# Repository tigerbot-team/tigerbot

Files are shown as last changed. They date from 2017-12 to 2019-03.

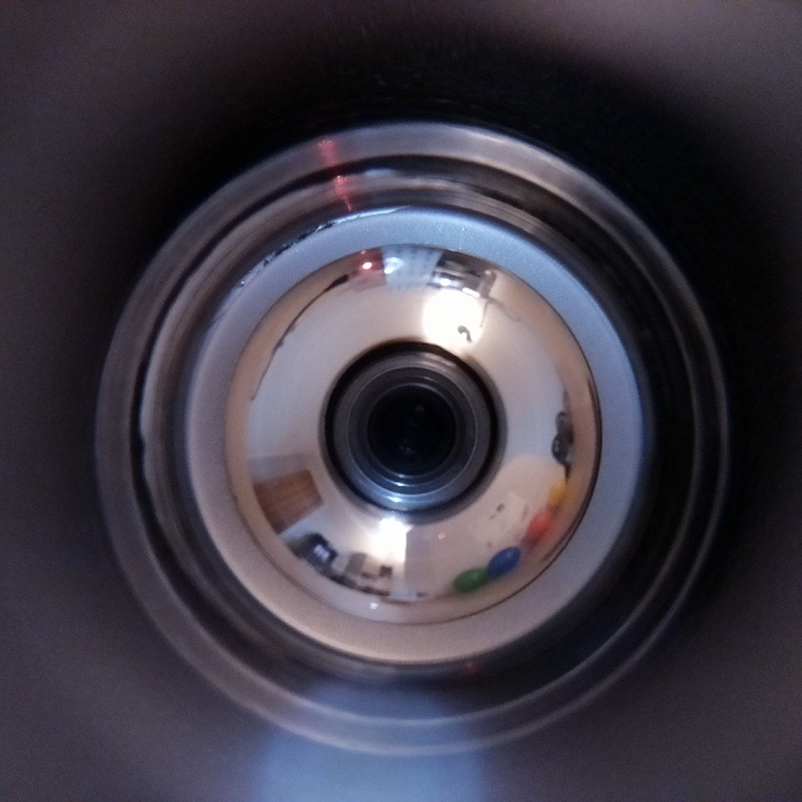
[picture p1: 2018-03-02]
camera-experiments/balls-polar.jpg

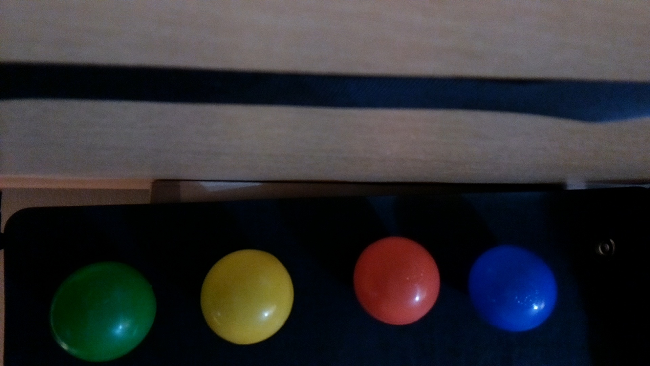
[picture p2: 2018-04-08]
camera-experiments/new-pics/last.jpg

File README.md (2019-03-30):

# tigerbot

- Building:
  - `make go-controller/bin/controller`
    - other targets: `make go-controller/bin/<target>`
   where targets in 
  `controller  ina219tests  joytests  screentests  servotests  spitests  toftests`
- Build image
  - `make go-controller-image`
- install
  - `make go-install-to-pi BOT_HOST=<pi IP>`
  - `make go-patch BOT_HOST=<pi IP>`
- run on Pi
  - ```
       docker run --rm -ti \
       -v `pwd`/controller:/controller \
       -v `pwd`/mb3.binary:/mb3.binary \
       -v /tmp:/tmp \
       -v /dev:/dev \
       --privileged \
       tigerbot/go-controller | tee controller.log
    ```

### Notes
- `toftests` binary needs to run inside container, so mount it in.

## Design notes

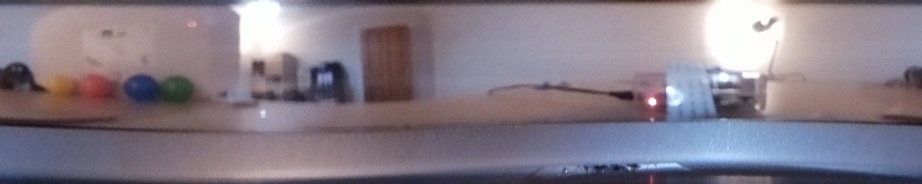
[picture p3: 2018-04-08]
pics/Feb18/unwarped-2031.jpg

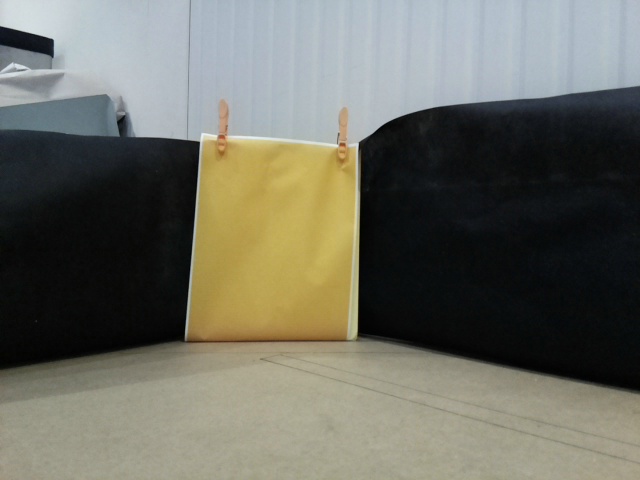
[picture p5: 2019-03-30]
nebula-captures/run-7-fail-yellow-green/nebula-image-4.jpg

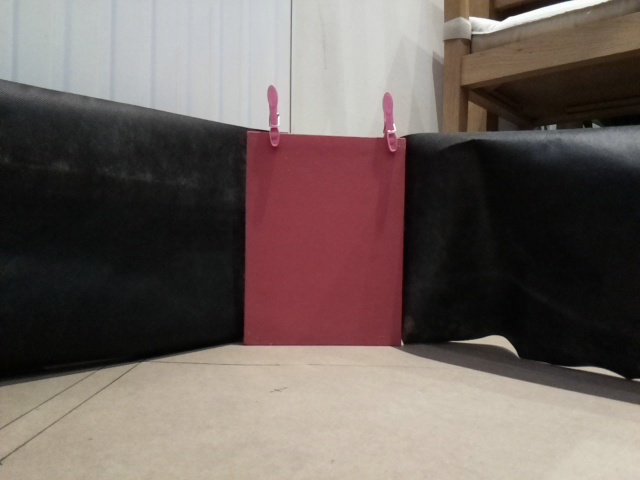
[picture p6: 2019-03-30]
nebula-captures/run-7-fail-yellow-green/nebula-image-1.jpg

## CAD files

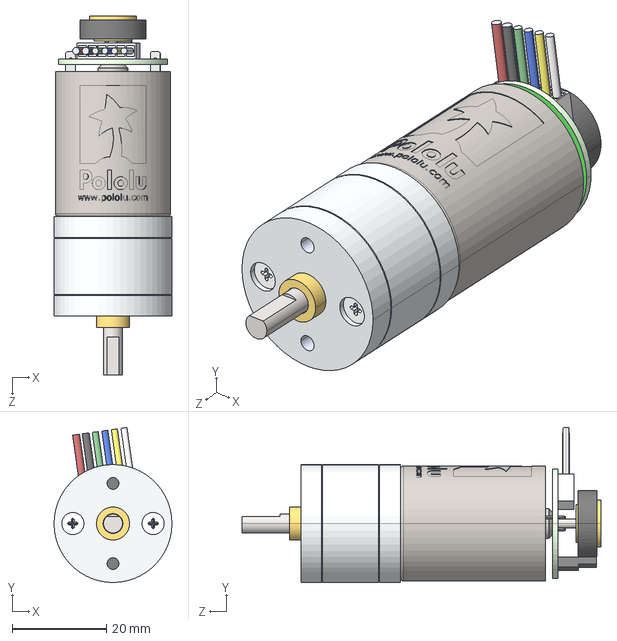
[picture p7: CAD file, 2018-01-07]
printed/cad/25d-metal-gearmotor-34-47-encoder.step
25.0 x 32.9 x 76.0 mm

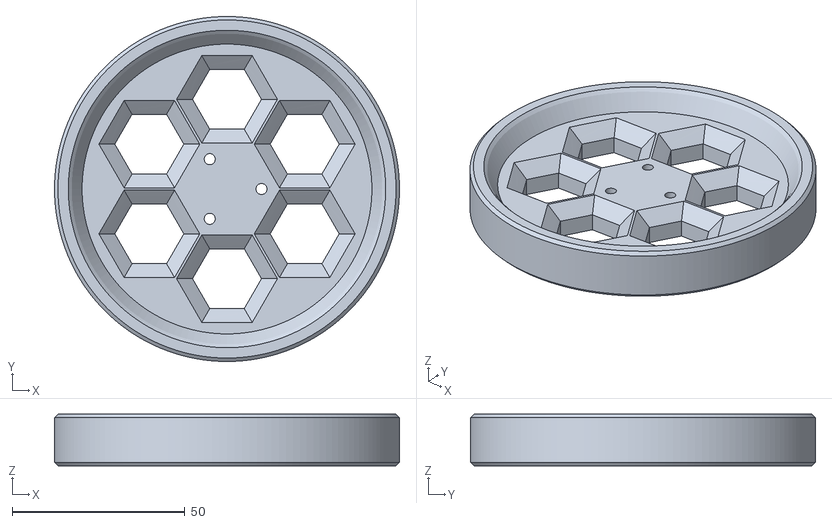
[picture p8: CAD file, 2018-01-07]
printed/stl/Wheel.stl
100.0 x 100.0 x 15.0

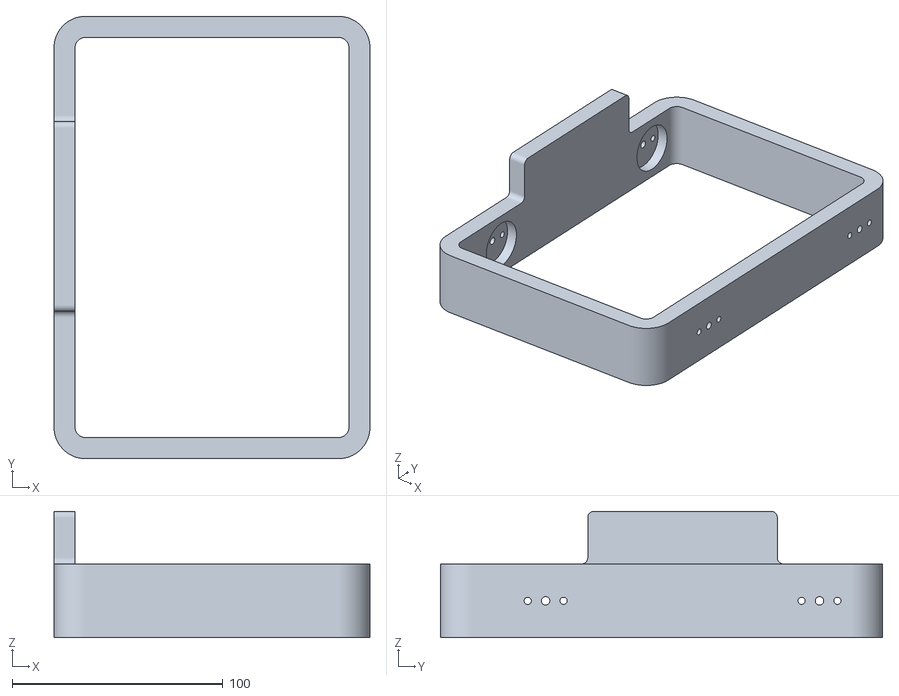
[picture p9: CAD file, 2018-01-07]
printed/stl/Chassis.stl
150.0 x 210.0 x 60.0

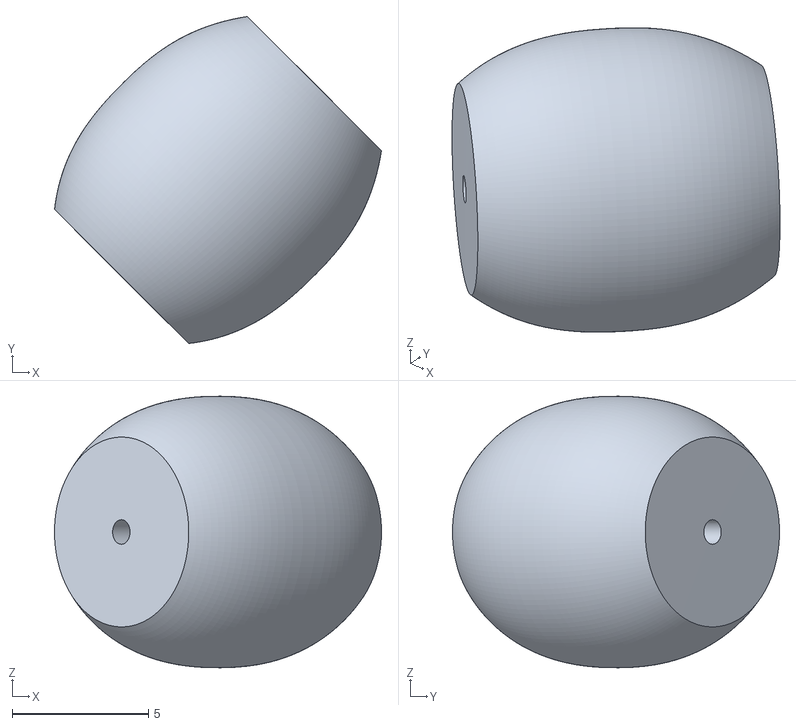
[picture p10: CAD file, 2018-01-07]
printed/stl/Part Studio 1 - Part 1.stl
12.0 x 12.0 x 9.96

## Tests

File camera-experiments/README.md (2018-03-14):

* Setup for running Python/OpenCV with camera on Pi

From a machine with an X server:

	ssh -X pi@<IP of Pi>

`-X` allows the Pi to run X applications (like OpenCV), with their windows
appearing on your host machine.

Then on the Pi, clone this repo, cd into it, and

	make run-container

Then in the container you can run Python code that accesses the camera and uses
OpenCV, imutils, numpy etc.  For example, to capture and show a single image:

	python test-image.py

(Code taken from
https://www.pyimagesearch.com/2015/03/30/accessing-the-raspberry-pi-camera-with-opencv-and-python/.)

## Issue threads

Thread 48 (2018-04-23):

IMU code will try a read that is > maximum I2C read length

fasaxc, 2018-04-23:
The FIFO buffer in the IMU is 512 bytes long but I2C can only read 256 bytes, maximum.

Might have been the cause of the heading issues.

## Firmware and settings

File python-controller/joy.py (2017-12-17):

import gobject  # needed for sending signals 
import struct  # needed for holding chunks of data 


class Joystick(gobject.GObject):
    """The Joystick class is a GObject that sends signals that represent 
    Joystick events"""
    EVENT_BUTTON = 0x01  # button pressed/released 
    EVENT_AXIS = 0x02  # axis moved  
    EVENT_INIT = 0x80  # button/axis initialized  
    # see http://docs.python.org/library/struct.html for the format determination 
    EVENT_FORMAT = "IhBB"
    EVENT_SIZE = struct.calcsize(EVENT_FORMAT)

    # we need a few signals to send data to the main 
    """signals will return 4 variables as follows: 
    1. a string representing if the signal is from an axis or a button 
    2. an integer representation of a particular button/axis 
    3. an integer representing axis direction or button press/release 
    4. an integer representing the "init" of the button/axis 
    """
    __gsignals__ = {
        'axis':
            (gobject.SIGNAL_RUN_LAST, gobject.TYPE_NONE,
             (gobject.TYPE_INT, gobject.TYPE_INT, gobject.TYPE_INT)),
        'button':
            (gobject.SIGNAL_RUN_LAST, gobject.TYPE_NONE,
             (gobject.TYPE_INT, gobject.TYPE_INT, gobject.TYPE_INT))
    }

    def __init__(self, dev_num):
        gobject.GObject.__init__(self)
        # define the device 
        device = '/dev/input/js%s' % dev_num
        # error check that this can be read 
        try:
            # open the joystick device 
            self.device = open(device)
            # keep an eye on the device, when there is data to read, execute the read function 
            gobject.io_add_watch(self.device, gobject.IO_IN, self.read_buttons)
        except Exception, ex:
            # raise an exception 
            raise Exception(ex)

    def read_buttons(self):
        """ 
        read the button and axis press event from the joystick device 
        and emit a signal containing the event data 
        """
        # read self.EVENT_SIZE bytes from the joystick 
        read_event = self.device.read(self.EVENT_SIZE)
        # get the event structure values from  the read event 
        time, value, event_type, number = struct.unpack(self.EVENT_FORMAT, read_event)
        # get just the button/axis press event from the event event_type
        event = event_type & ~self.EVENT_INIT
        # get just the INIT event from the event event_type
        init = event_type & ~event
        signal = None
        if event == self.EVENT_AXIS:
            signal = "axis"
        elif event == self.EVENT_BUTTON:
            signal = "button"
        if signal:
            # print("%s %s %s %s" % (signal,number,value,init) )             
            self.emit(signal, number, value, init)

        return True


if __name__ == "__main__":
    try:
        j = Joystick(0)
        loop = gobject.MainLoop()
        loop.run()
    except Exception, e:
        print(e)

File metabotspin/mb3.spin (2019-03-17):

{{
///////////////////////////////////////////////////////////////////////////////////////////////////////////////////////////////
// METABOT3 Motor Controller
//
// I2C interface : registers
//      0 :     Motor 0 position (4 bytes)
//      4 :     Motor 1 position (4 bytes)
//      8 :     Motor 2 position (4 bytes)
//      12 :    Motor 3 position (4 bytes)
//      16 :    Left Ping distance in mm (2 bytes)
//      18 :    Right Ping distance in mm (2 bytes)
//      20 :    Front Ping distance in mm (2 bytes)
//      22 :    Target Motor 0 Speed (1 byte) signed -127 - 127
//      23 :    Target Motor 1 Speed (1 byte)
//      24 :    Target Motor 2 Speed (1 byte)
//      25 :    Target Motor 3 Speed (1 byte)
//      26 :    Options (low bit = autoping on / off)
//      27 :    Ball Thrower Motor Speed 1
//      28 :    Ball Thrower Motor Speed 2
//      29 :    Ball Thrower Servo 1
//      30 :    Ball Thrower Servo 2
//      31 :    Read Ready (master sets to 1 when ready to read, slave sets to zero when multi-byte values updated
// 
///////////////////////////////////////////////////////////////////////////////////////////////////////////////////////////////
}}

CON
  _CLKMODE = xtal1 + pll16x
  _XINFREQ = 6_000_000
  debuglim = 8
  posbase = 0
  pingbase = 16
  speedbase = 22
  options = 26
  ballmotor1 = 27
  ballmotor2 = 28
  servo1 = 29
  servo2 = 30
  readready = 31
  motorshutdowntime = 100
  maxpwmramp = 50
  maxspeed = 500

OBJ
  quad :  "encoder"
  pwm : "pibal_pwm"
  i2c : "I2C_slave"
  ping : "Ping"

DAT
'       M1   M2   M3   M4
' encA  A1   A10  A15  A29
' encB  A0   A11  A14  A28
' dir   A3   A12  A18  A26
' pwm   A2   A13  A17  A27

' Motor driver connector: DIR, PWM, GND
' Motor connector: encA, encB, +ve, gnd, M+, M-

  encoderPins byte 0, 1, 10, 11, 15, 14, 28, 29
  motorPWM    byte 2, 13, 17, 27
  motorD1     byte 3, 12, 18, 26

' Pinger pins  
  trigPins      byte 4, 6, 8
  echoPins      byte 5, 7, 9

' Servo Pins - 19, 20, 21, (22) (22 is a copy of 21)

VAR
  long  pidstack[80]
  long  pingstack[30]
  word  pingval[3]
  long  lastpos[4]
  long  debug[debuglim]
  long  actual_speed[4]
  byte  time_at_zero[4]
  long  error_integral[4]
  long  error_derivative[4]
  long  millidiv
  long  servozero
  long  servofactor
  long  motorfactor
  long  millioffset
  long  Kp
  long  Ki
  long  Kd
  byte  b
  long  lastping
  long  pingcog
  
  ' vars for servo program      
  long  position1, position2, position3, position4    'The assembly program will read these variables from the main Hub RAM to determine
                                           ' the high pulse durations of the three servo signals                 
  
PUB main
  millidiv := clkfreq / 1000

  servozero := millidiv * 80 / 100      ' Minimum servo pulse width.  This should be 1ms but we stretch it a little
                                        ' for slightly greater travel.
  servofactor := millidiv * 140 / 25600 ' Scale factor from servo units to pulse time.
  motorfactor := millidiv / 256         ' Scale factor from servo units to motor pulse time.

  Kp := 60
  Ki := 10
  Kd := 15
  lastping := cnt

  ' Since we pre-calculate the servo delays in this thread we need to set them before we start the servo control cog.
  position1 := millidiv
  position2 := millidiv
  position3 := servozero + (127 * servofactor)
  position4 := servozero + (127 * servofactor)

  p1:=@position1                           'Stores the address of the "position1" variable in the main Hub RAM as "p1"
  p2:=@position2                           'Stores the address of the "position2" variable in the main Hub RAM as "p2"
  p3:=@position3                           'Stores the address of the "position3" variable in the main Hub RAM as "p3"
  p4:=@position4                           'Stores the address of the "position4" variable in the main Hub RAM as "p3"

  waitcnt(millidiv + cnt)

  cognew(@ThreeServos,0)                   'Start a new cog and run the assembly code starting at the "ThreeServos" cell         

  millioffset := negx / millidiv * -1
  i2c.start(24,25,$42)                                ' (COG 2)  Start I2C using pins 24 CLK / 25 DAT at address 0x42
  quad.Start(@encoderPins)                            ' start the quadrature encoder reader (COG 3)
  resetMotors                                         ' reset the motors
  pwm.start_pwm(motorPWM[0], motorPWM[1], motorPWM[2], motorPWM[3], 20000)    ' start the pwm driver (COGS 4 & 5)
  cognew(pid, @pidstack)                              ' COG 6
  pingcog := cognew(autoping, @pingstack)              ' COG 7 (last one)
  repeat
    update
    waitcnt(millidiv + cnt)
    ' check pinger timeout and restart cog if it has fired
    'if (cnt - lastping)  >  ((clkfreq / millidiv) * 100)
    '  coginit(pingcog, autoping, @pingstack)
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

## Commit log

2017-12-31 Add propellor fw
2018-01-01 Add propellor code for monorepo
2018-01-07 Add hardware files
    [25d-metal-gearmotor-34-47-encoder.step, Chassis.stl, Part Studio 1 - Part 1.stl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]
2018-01-07 Update python code to use I2C
2018-01-13 Update propellor code to latest
2018-01-13 Remove broken encoder hack
    [mb3.spin]
2018-01-13 Swap round encoder pins to make them count in same direction as motor
    [i2ctest.py, mb3.spin]
2018-01-13 Remove prints, add logs
2018-02-04 Document more buttons on controller.
2018-02-04 WiP on i2c
2018-02-04 Get 12c to propeller working from go
2018-02-04 Switch to 4-motor test program.
2018-02-04 Add mode system: Options button switches mode.
2018-03-03 Setup for running Python/OpenCV with camera on Pi
2018-03-10 Stub out propeller, add config for joystick device
2018-03-10 Get openCV linked into the controller
    Add camera to test mode.
2018-03-15 Attempt at own TOF driver
2018-03-15 WiP on adding C-library for TOF sensor
2018-03-15 Get tof sensor library linked in (not using it yet).
2018-03-17 Add support for continuous TOF sensor mode.
2018-03-18 Switch to anti clockwise
2018-03-19 Adjust mixer for side-translating wheels.
2018-03-24 Set a half-second limit on how long a motor is at 0 speed before we turn it off.
2018-03-24 Drive the propeller reset pin to avoid noise triggered resets.
2018-03-24 Program propeller form go, reflash propeller after crash.
2018-03-24 Zero out motors if desired speed is low for long enough.
2018-03-28 Put motor PWM out of phase to reduce syncronised current draw
2018-03-31 Add support for extra ToF sensors, renumber sensors.
2018-03-31 Limit PWM ramp to reduce current draw when switching direction.
2018-03-31 PID loop for maze
2018-03-31 Go back to simple squared error. Add front sensors to distance.
2018-04-07 Fix servo timings, switch to 4 x 8-bit servos.
    [mb3.spin]
2018-04-08 Add sample pics
2018-04-08 Fix that servos didn't work until timer had wrapped.
    Still not sure of exact cause.
    [mb3.spin]
2018-04-08 Add servo control to RC mode.
2018-04-08 Extend servo range to 800-2200us
2018-04-08 Split servo control into its own struct.
2018-04-08 Make share button cycle through modes in opposite order.
2018-04-08 Tune pitch auto-repeat
2018-04-08 Fix motor mappings.
2018-04-08 Test reading from camera and looking for orange ball in a loop
2018-04-14 Show supported video props
2018-04-14 Add IMU.
2018-04-14 Stop motors when finished
2018-04-14 Tune duck shoot mode.
    - fix motor PWM timings
    - soften rotation
    - limit servo values.
    [mb3.spin]
2018-04-15 WiP on adding IMU to RC mode
2018-04-15 Skip frames if code falls behind camera
2018-04-15 Rework reversing so it works for ball lost case too
2018-04-15 Take a picture when circle button pressed
2018-04-15 Fix mux bindings for new front mount.
2018-04-15 Add ToF sensors to rainbow mode.
2018-04-16 Tuned IMU RC mode
2018-04-17 Reduce IMU loop to 20ms and tune.
2018-04-18 Switch to IMU Y axis. Tune IMU expo.
2018-04-19 Fix left/right sensor mappings.
2018-04-19 IMU-based SLST
2018-04-19 Implement release button to go for SLST mode.
2018-04-21 IMU maze mode
2018-04-21 Add mode-switch sounds
2018-04-21 Actually filter on Y coord (subject to config)
2018-04-21 Fix sample rate; update ready.wav
2019-01-12 Update motor3 encoder pin to match PCB
2019-01-26 Move IMU onto SPI bus.
2019-02-09 Fix size of IMU read buffer. SPI can handle 4096 byte transfers.
2019-02-09 WiP on SPI. spitests now writes images, shares bus.
2019-02-16 Adapt code for Wall-e chassis. RC mode almost working.
2019-03-02 Add support for moving ToF sensor address.
2019-03-03 Fix INA219 current/power
2019-03-03 Rework ToF sensors to return 2001mm on range invalid.
2019-03-03 Various fixes: working RC mode on refactored I2C loop.
2019-03-03 Fix up IMU calibration and heading hold mode.
2019-03-09 Tune propeller PID for new motors.
2019-03-09 Add motor encoder reading to the go code.
2019-03-09 Get screen showing voltages.
2019-03-10 Add servo control.
2019-03-11 Fix servo controller driver.
2019-03-11 Fix servo driver auto-increment.
2019-03-16 Different shunt values for each sensor.
2019-03-16 Shut down servos when stopping.
2019-03-16 Heading hold tweaks; reduce throttle delta.
2019-03-16 Limit maximum motor PWM
2019-03-17 Flash power warning. Fix bar colour.
2019-03-17 Limit max motor power.
2019-03-17 Run I2C loop even if servos aren't present.
2019-03-23 Tune for 9.7:1 motors
2019-03-23 Pin to the sgtwilko/rpi-raspbian-opencv that Shaun has
2019-03-23 Export motor distances
2019-03-23 Switch control channels to wait groups
2019-03-24 Clamp target heading to +/- 180 of current heading.
2019-03-24 Use motor encoders for nebula mode
2019-03-30 Add colour confirmation logic
    If we are allowed to do colour confirmation, the procedure is to press
    joystick.ButtonCircle while Wall-E is moving towards a correct colour.
2019-03-30 Protect against multiple button presses while advancing
2019-03-30 Protect against button press outside advancing phase
2019-03-30 Code mode to just take pictures of the four colour boards
2019-03-30 Increase pitch range
